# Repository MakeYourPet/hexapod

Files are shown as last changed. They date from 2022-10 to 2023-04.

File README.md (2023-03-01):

##
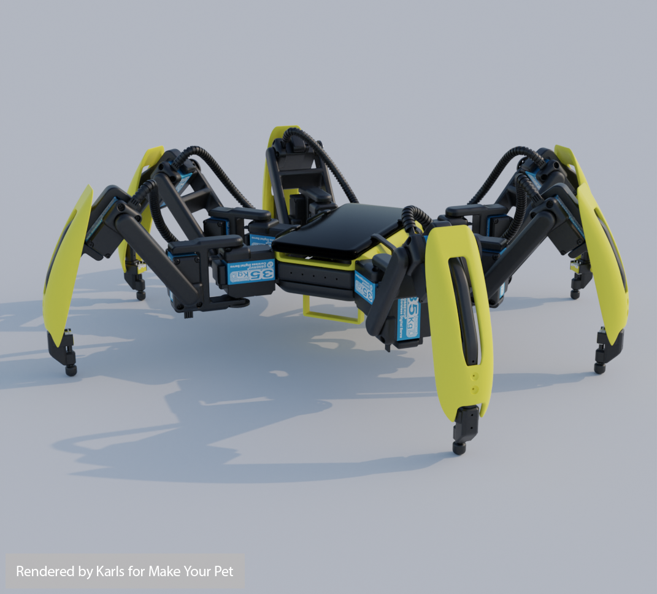
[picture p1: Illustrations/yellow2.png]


## Some quick links to get you started
- Watch the step by step build videos on my [YouTube channel](https://www.youtube.com/makeyourpet).<br>
- For build questions and to connect with the community join my [Discord server](https://discord.gg/vb8YWMfBuk).<br>
- A [wiring diagram](/wiring-diagram-servo2040.png) that you may find useful.<br>
- A fan-made [parts list](https://docs.google.com/spreadsheets/d/1jLi3IdmLERsBDhjaqHxFGQgZul_3uq9oj55M1rFG8mY/edit#gid=0). Also another fan-made [parts list](https://docs.google.com/spreadsheets/d/1y--z7EeejWcb-8ooPaIFn3Hulu9dJOcoKyGoxGq8KI8/edit?usp=drivesdk). And here is a [third one](https://github.com/LonelyGhost6/Public/blob/main/part-list.pdf). These are not meant to be a complete list of EVERYTHING that you need, but they cover most of the important and pricier stuff.<br>
- If you decide to use the Servo2040 board (highly recommended), find the [firmware](https://github.com/EddieCarrera/chica-servo2040-simpleDriver/releases/download/v0.0.1/chica-servo2040_release.uf2) and the [instructions on how to flash it](https://github.com/EddieCarrera/chica-servo2040-simpleDriver#loading-the-firmware-image) from Eddie's repository.<br>
  
## Illustrations
<p float="left">
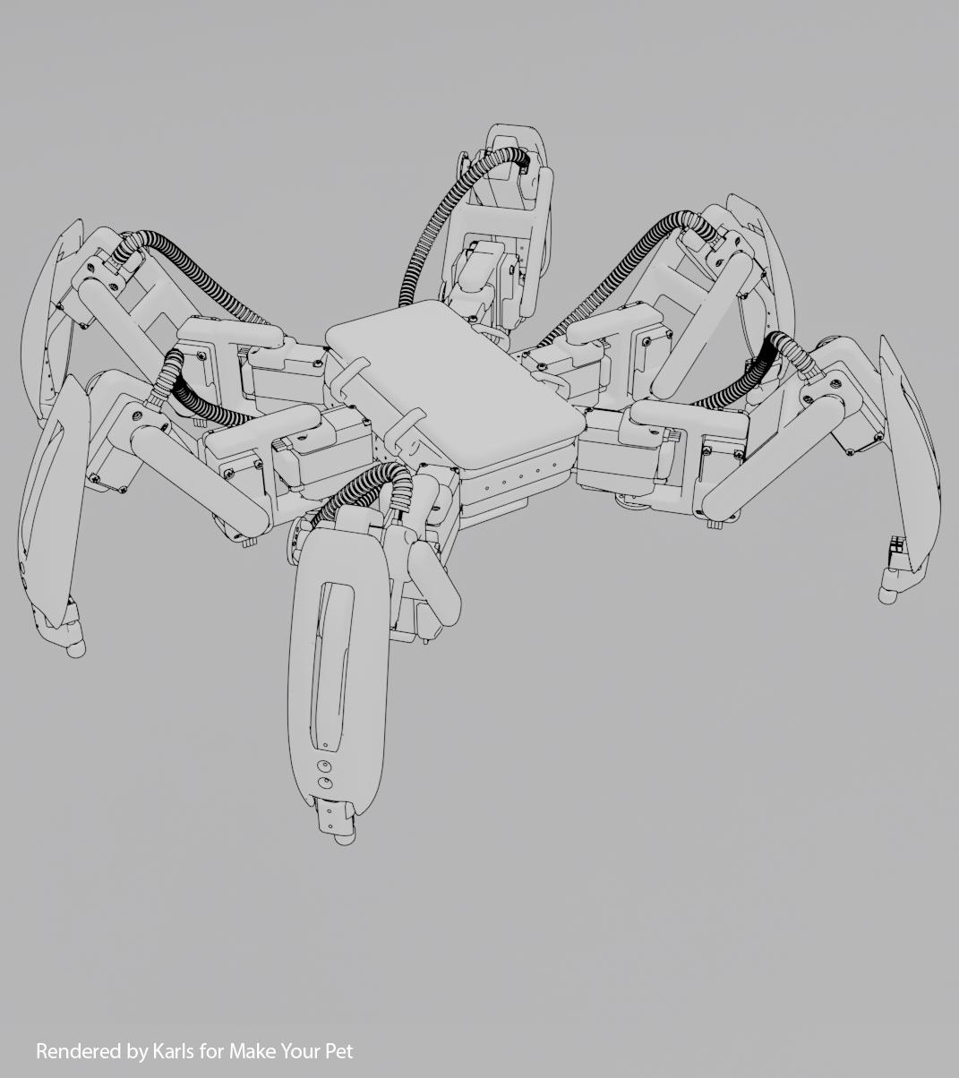
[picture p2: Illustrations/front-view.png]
  
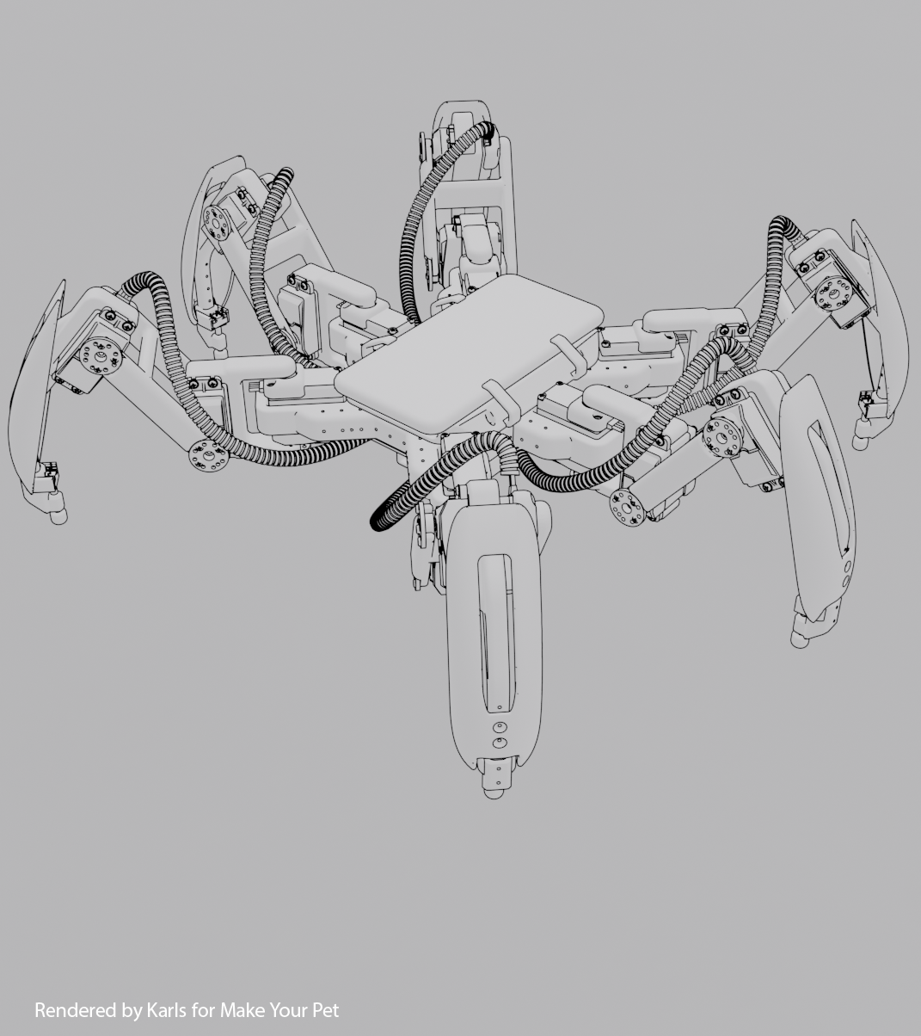
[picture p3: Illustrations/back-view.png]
  
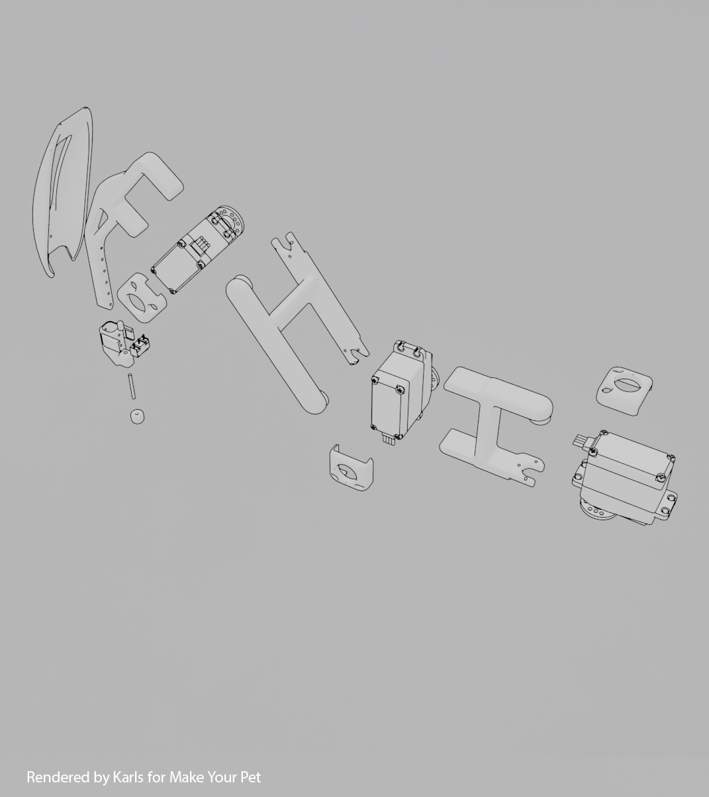
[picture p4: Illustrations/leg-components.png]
  
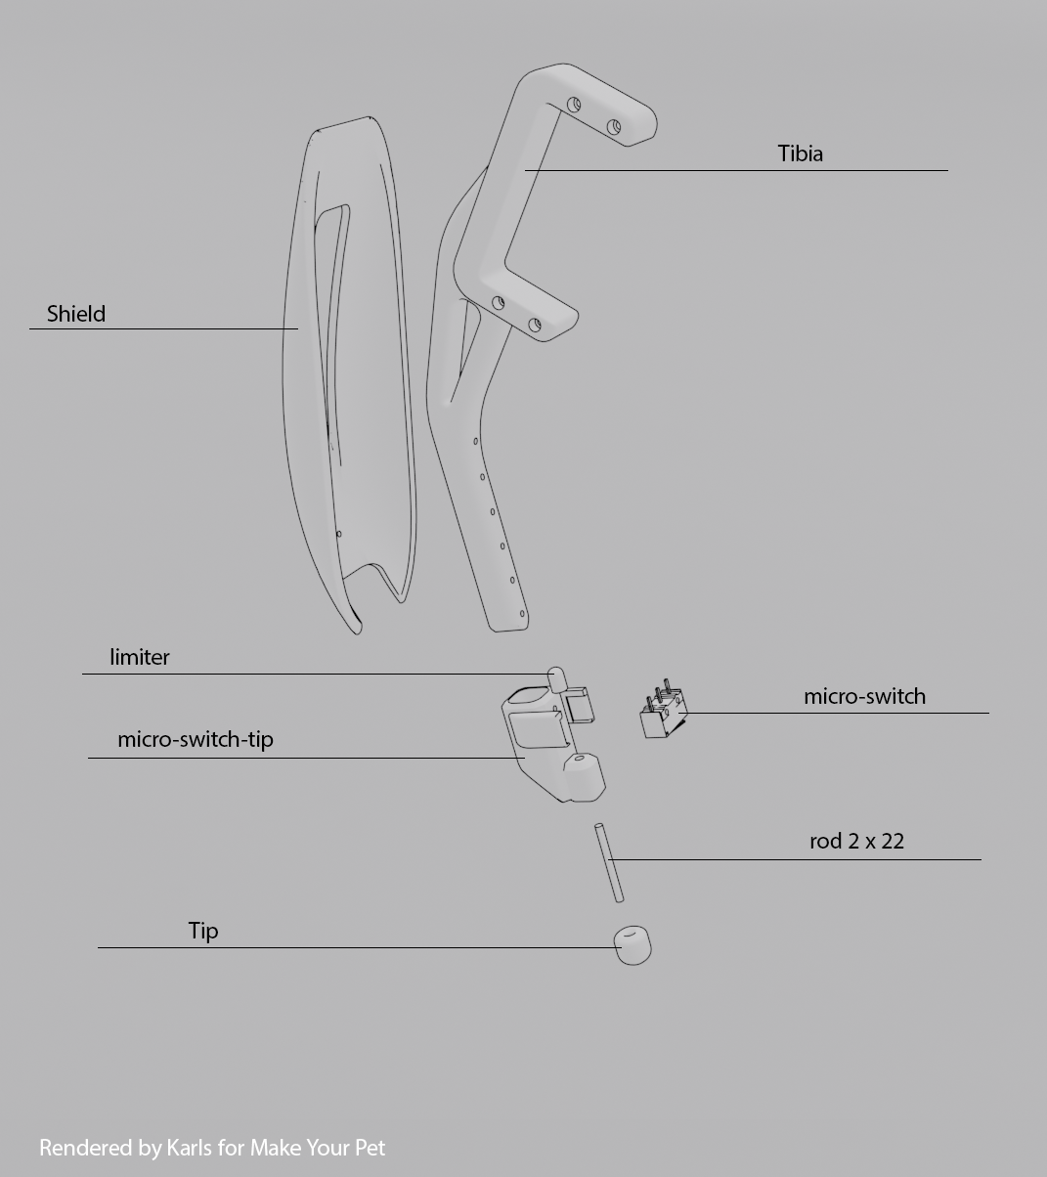
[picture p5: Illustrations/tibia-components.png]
  
</p>

## About the STL files in this repository
Some of the parts have multiple versions with slight differences. But all of them are compatible and should work.  
Make sure to check all of them to pick the one that works for you before committing to the print.  
I use the latest version of each part in my own hexapod, which is the one with the higher number at the end of its name.

## Compatible fan-made 3D printable parts
Check out [this](https://github.com/almelnz2005/hexapod) repository which contains modified (but compatible) versions of the original parts which uses metal horns, M3 screws and seperated components to make the parts more 3D printer friendly. This is especially helpful if you are printing with material other than PLA and have issues with supports or shrinking.

## Wiring Diagram
- Pimoroni Servo2040 (The newer, simpler, cheaper and recommended option):<br>
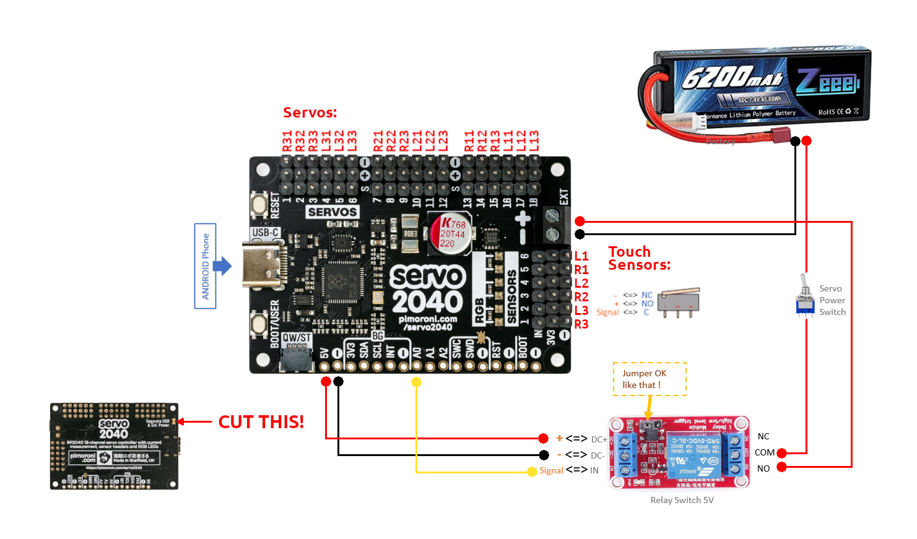
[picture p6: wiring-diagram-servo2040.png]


- Pololu Maestro (The original, complicated, expensive and legacy option):<br>
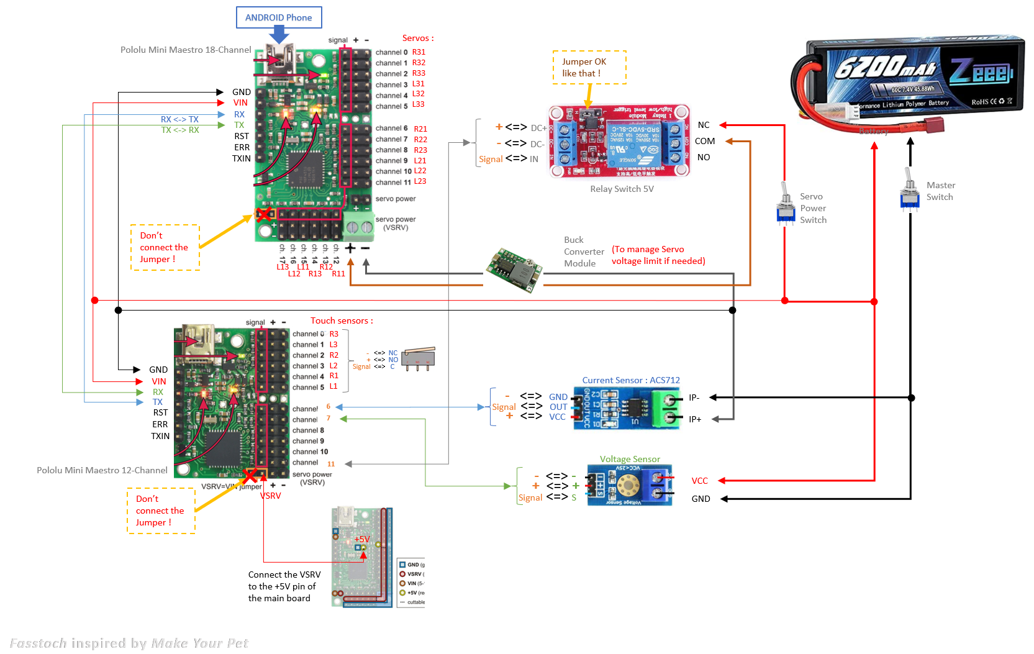
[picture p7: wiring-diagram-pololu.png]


## Electronic Component Layout
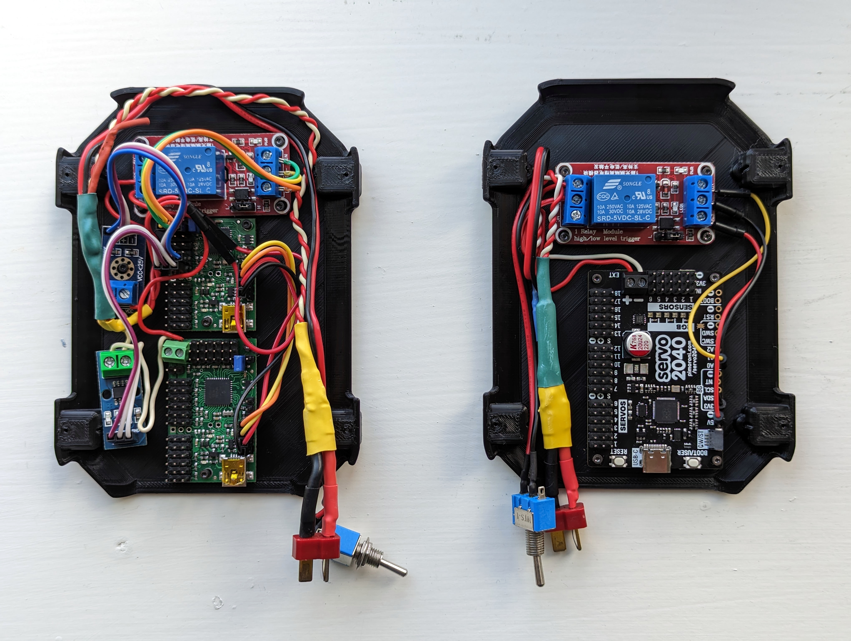
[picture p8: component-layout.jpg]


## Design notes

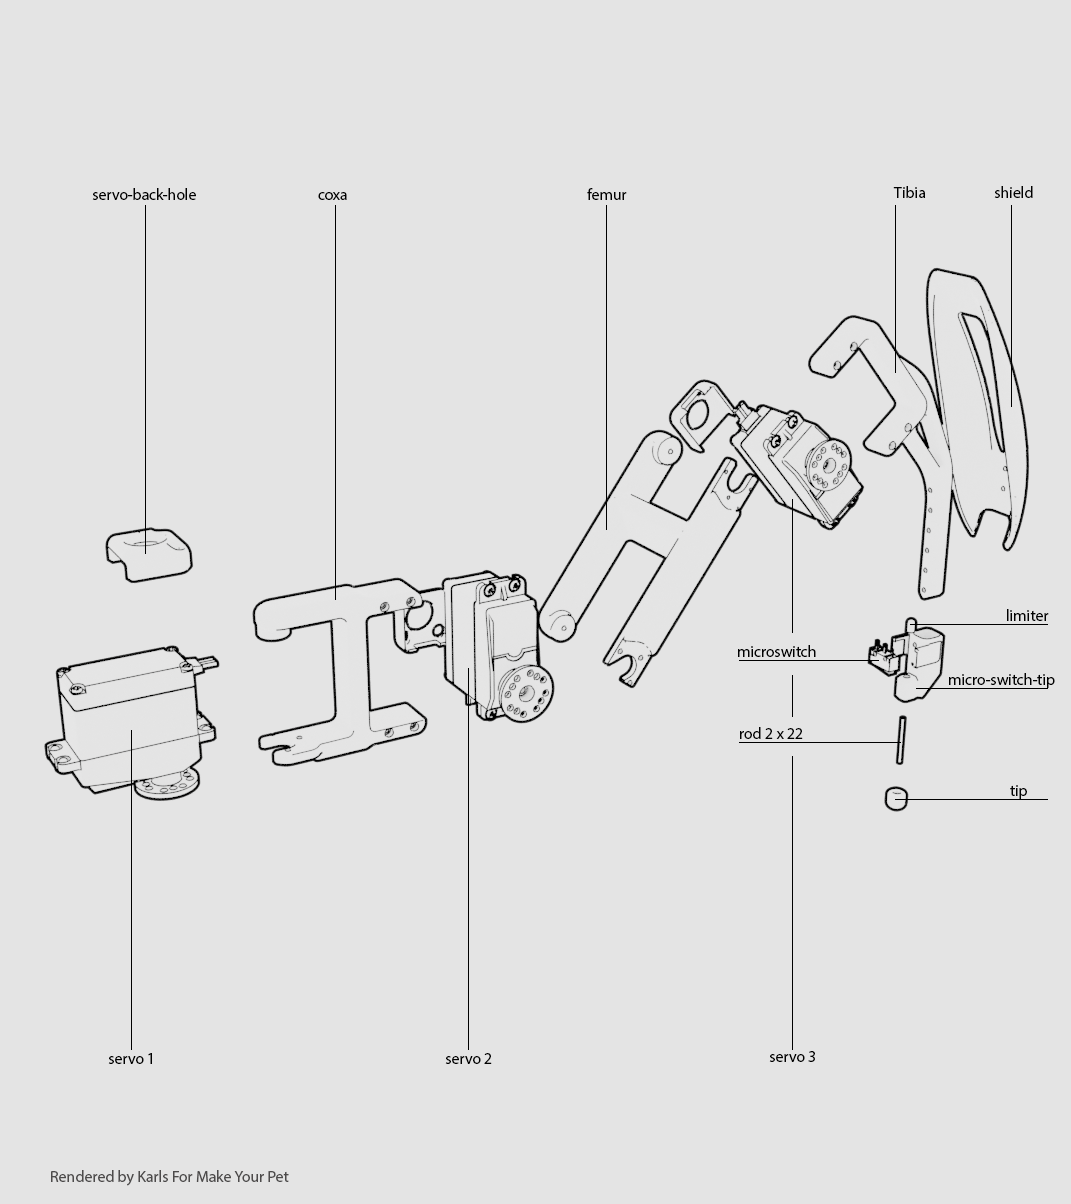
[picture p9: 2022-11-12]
Illustrations/leg.png

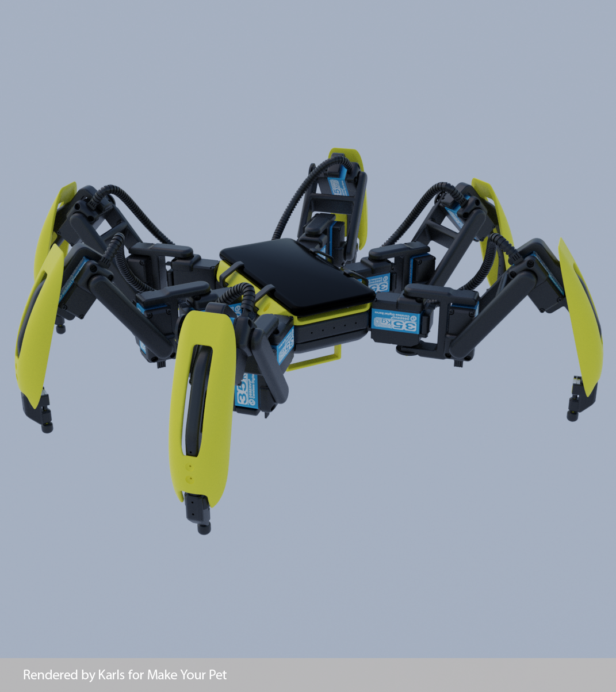
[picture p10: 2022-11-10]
Illustrations/yellow.png

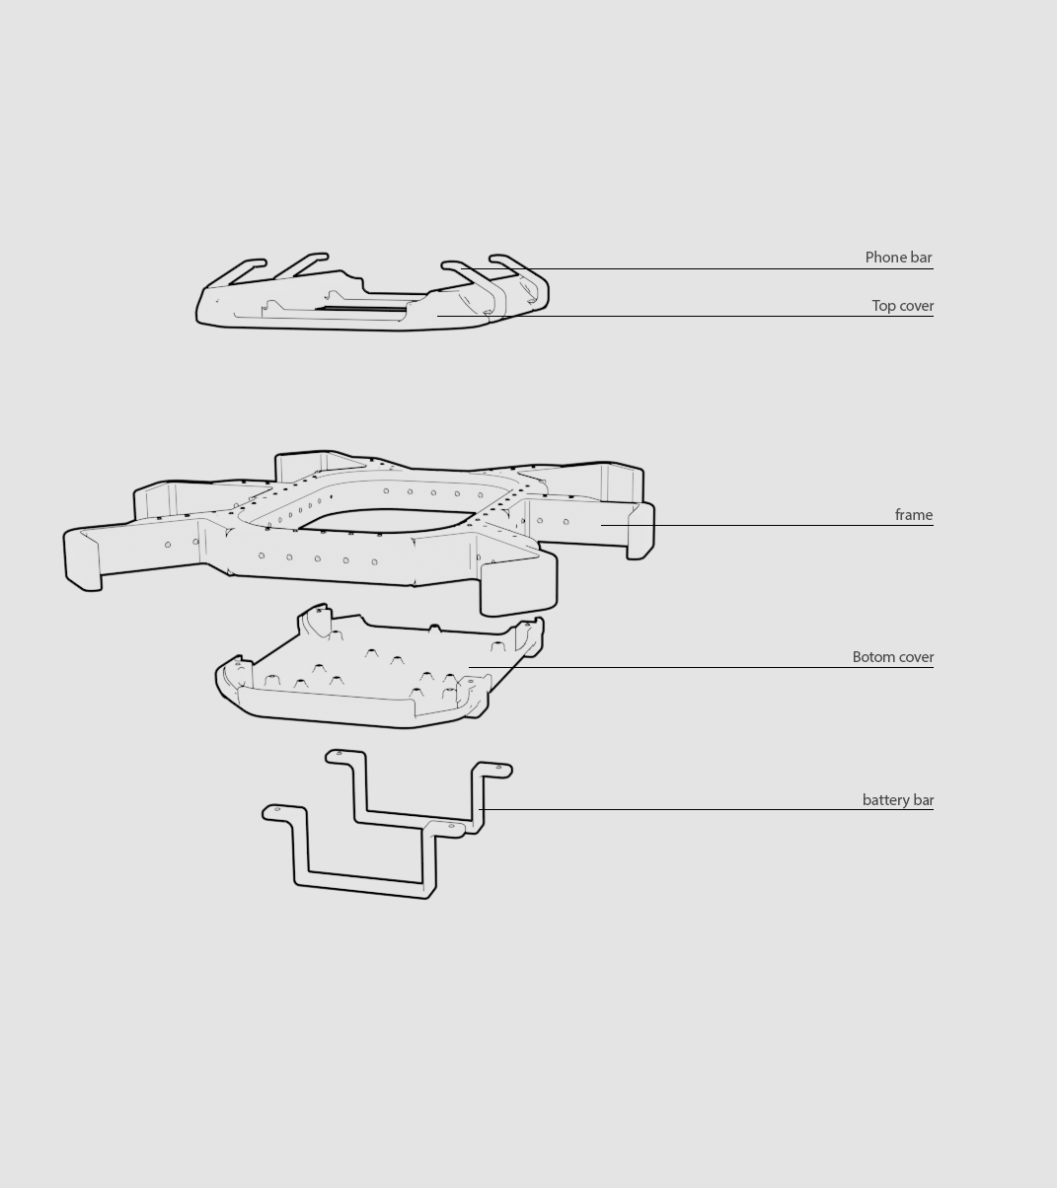
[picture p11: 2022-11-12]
Illustrations/body.png

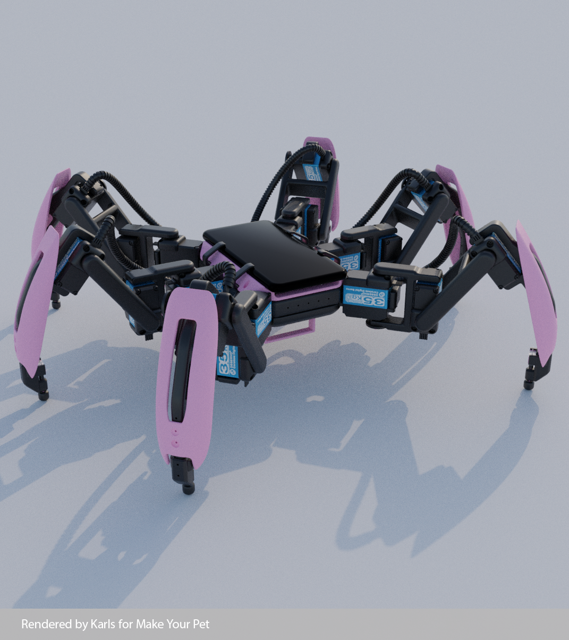
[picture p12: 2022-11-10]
Illustrations/Pink.png

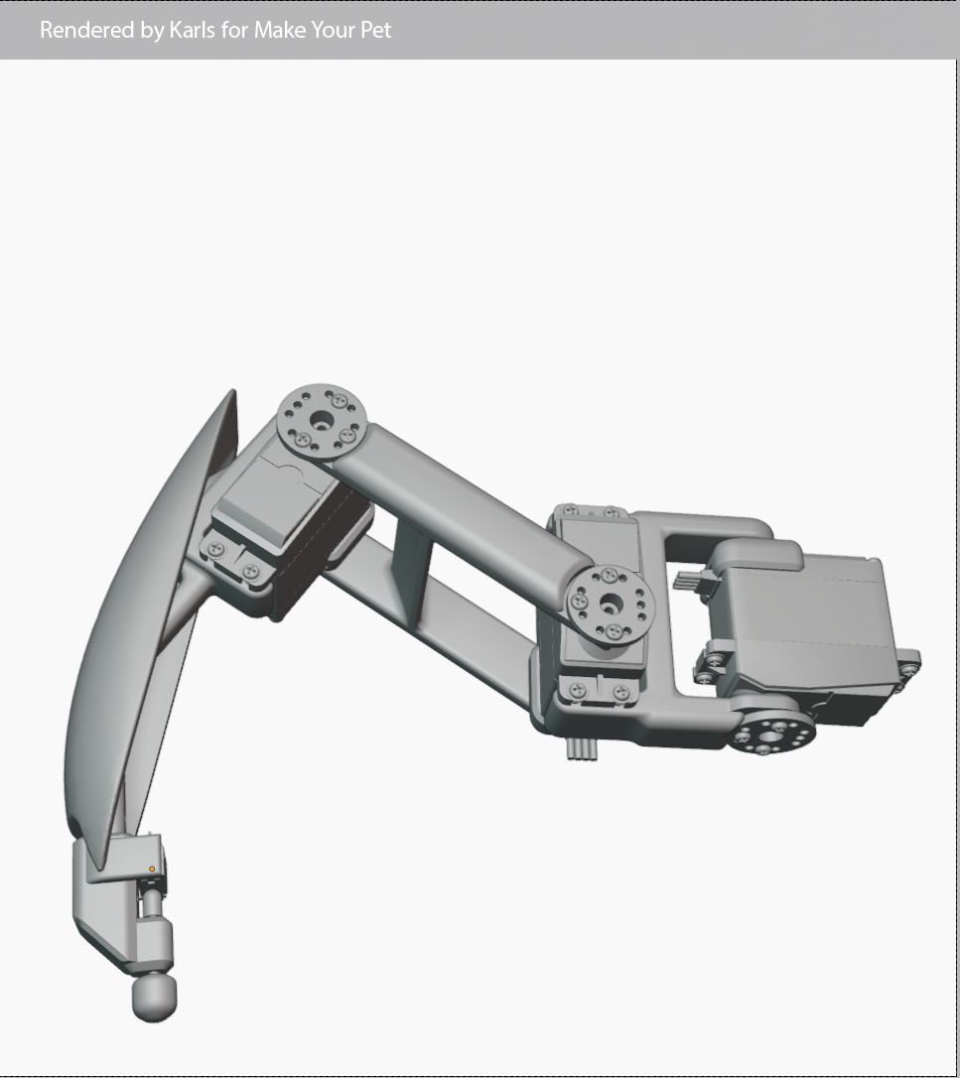
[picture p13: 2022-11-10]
Illustrations/servo_orientation.png

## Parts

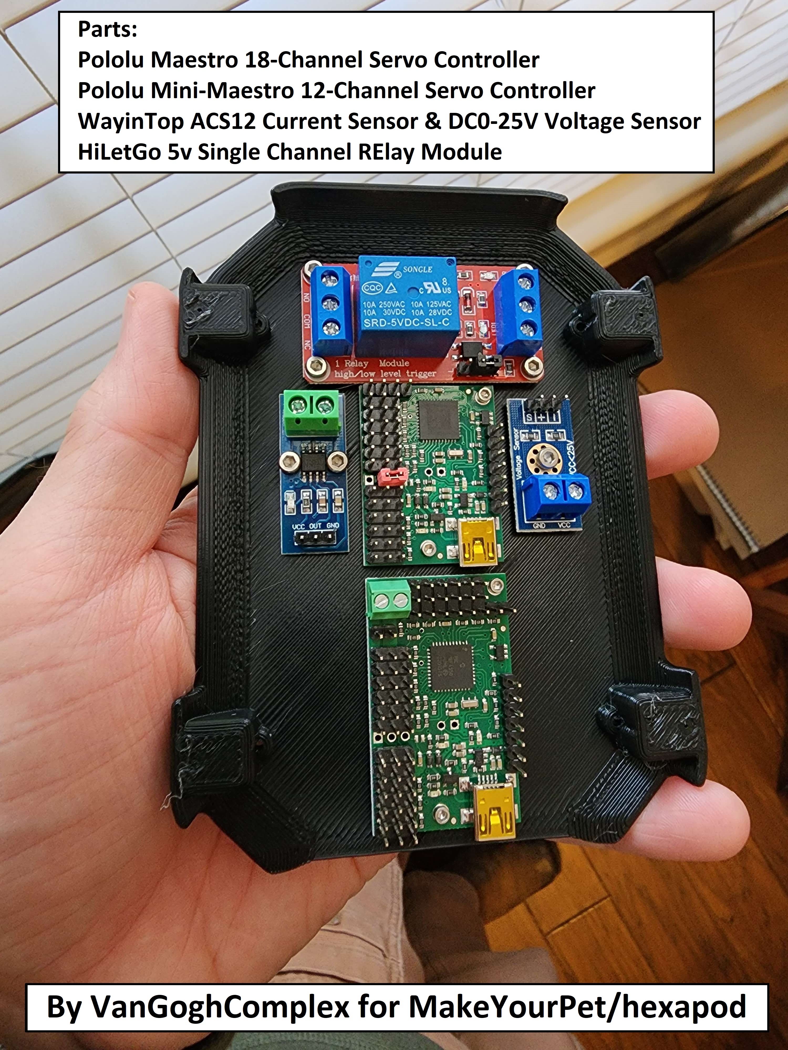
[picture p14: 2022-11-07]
component-layout-pololu.jpg

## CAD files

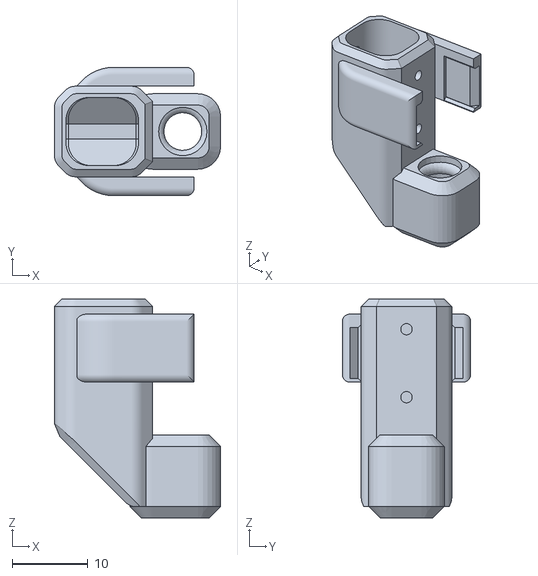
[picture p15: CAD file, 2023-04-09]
Chipo/ms-holder.stl
22.0 x 17.0 x 29.0

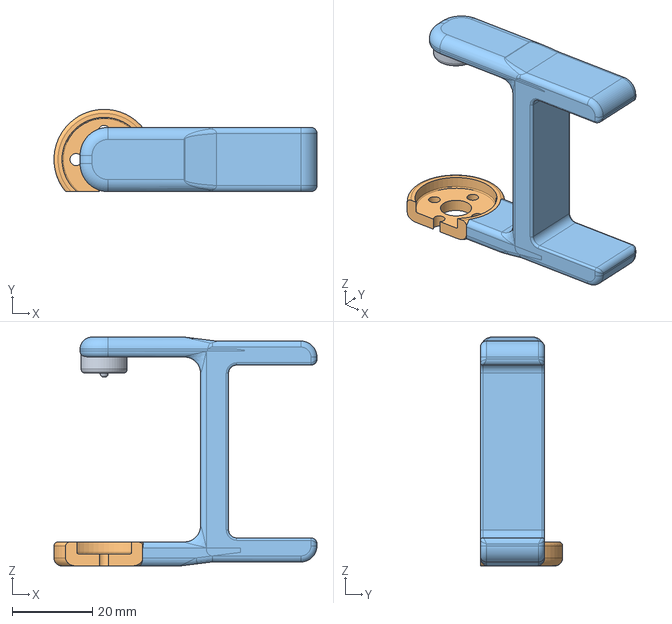
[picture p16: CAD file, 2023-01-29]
Metal Horn/STEP/coxa.step
65.5 x 20.5 x 57.0 mm

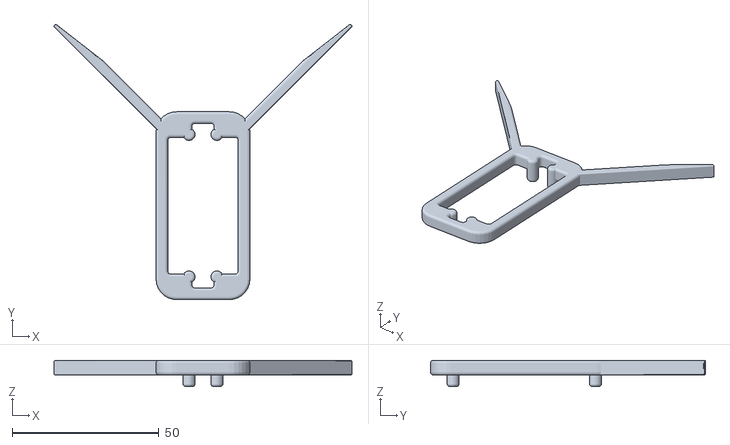
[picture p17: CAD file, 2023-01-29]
Metal Horn/STL/calib-ruler.stl
101.5 x 93.8 x 9.00

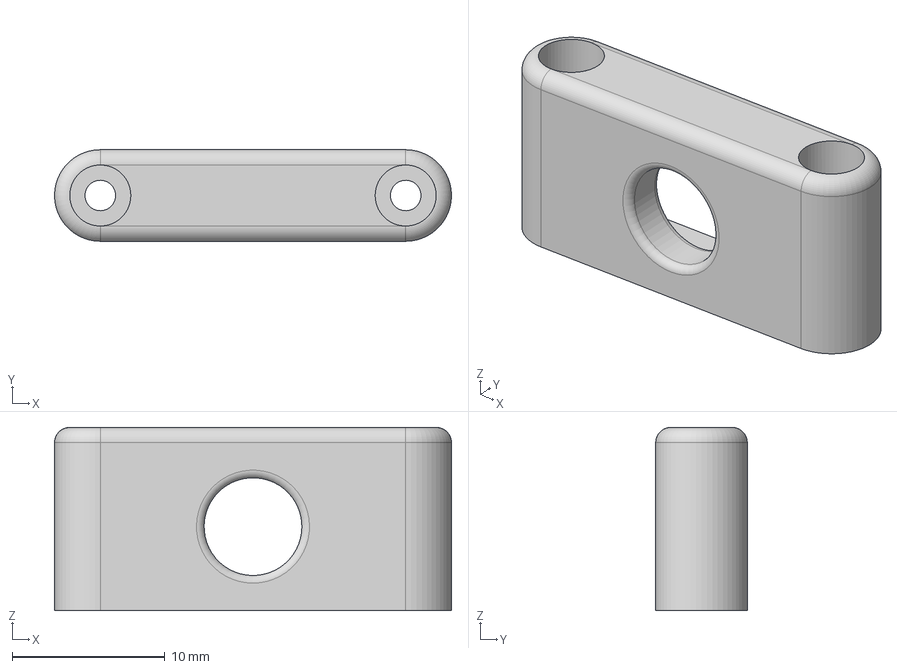
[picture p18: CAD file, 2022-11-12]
STEP/switchmount.step
26.0 x 6.00 x 12.0 mm

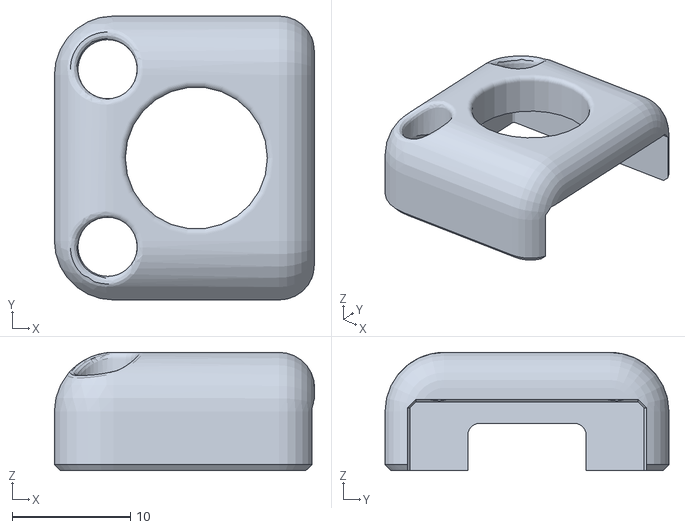
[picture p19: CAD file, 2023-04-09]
Chipo/idler.stl
22.0 x 24.0 x 10.0

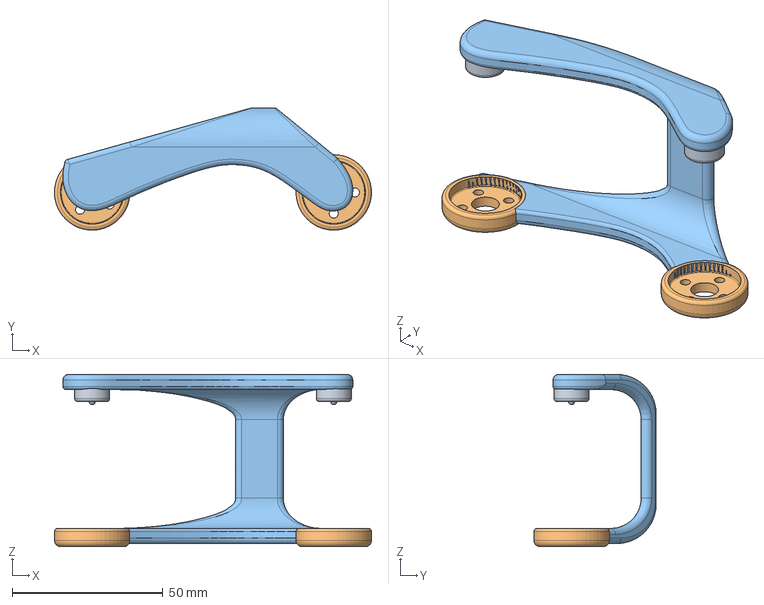
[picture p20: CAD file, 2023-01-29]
Metal Horn/STEP/femur.step
105.0 x 40.5 x 57.0 mm

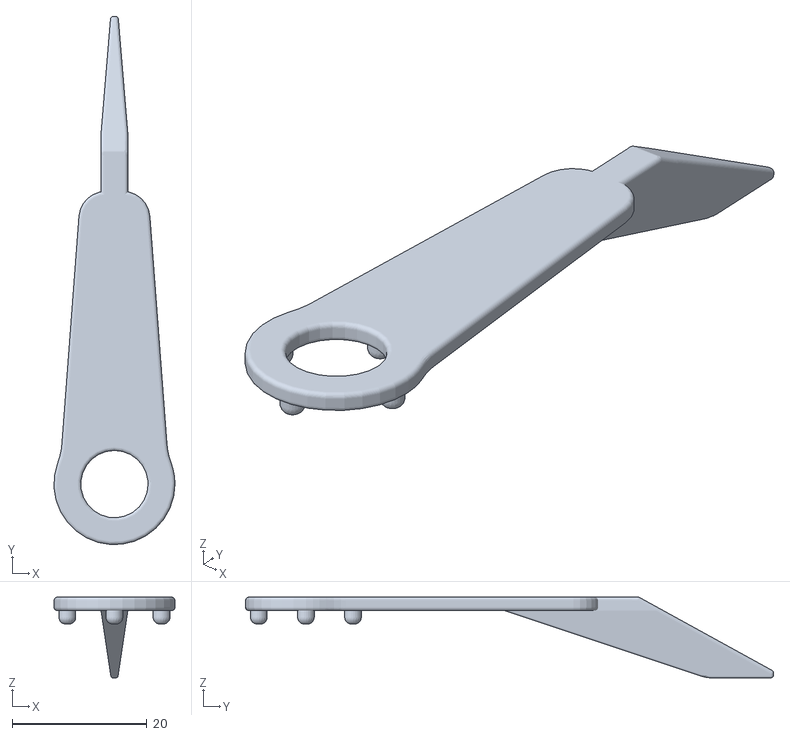
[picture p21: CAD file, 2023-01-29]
Metal Horn/STL/calib-arm.stl
18.0 x 78.5 x 12.0

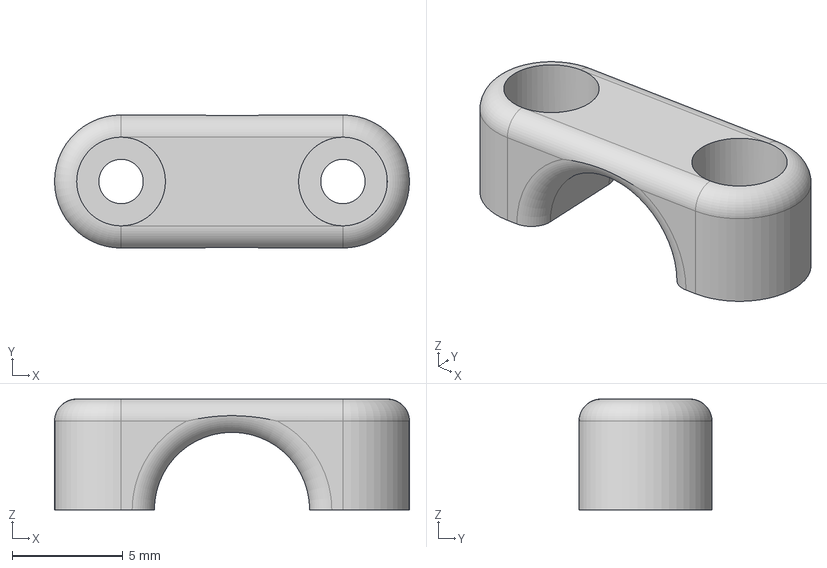
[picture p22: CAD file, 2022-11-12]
STEP/ziptiebase.step
16.0 x 6.00 x 5.00 mm

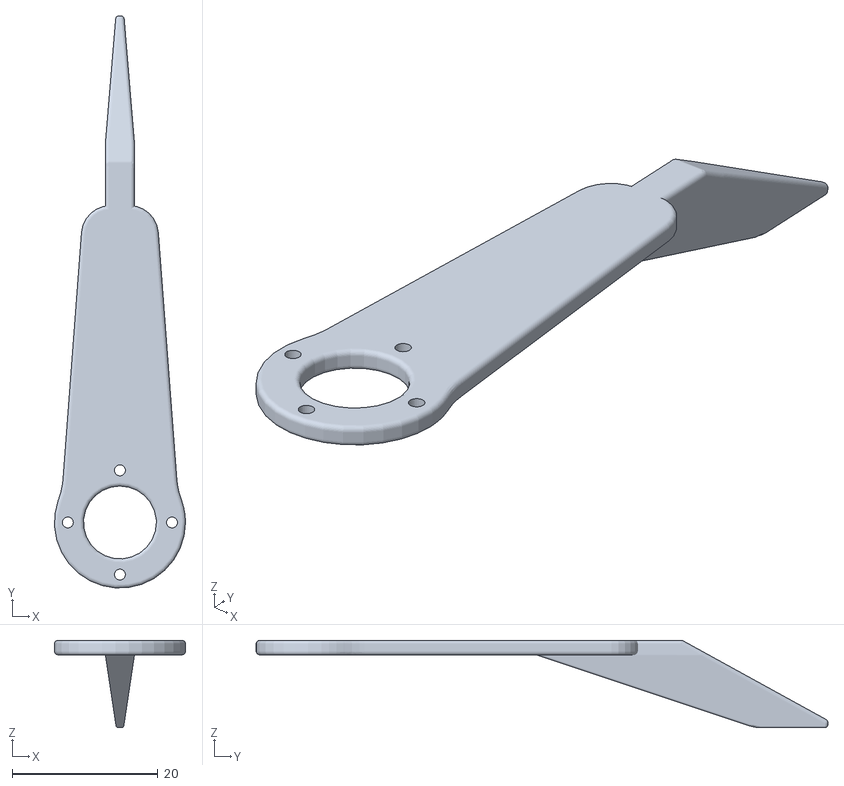
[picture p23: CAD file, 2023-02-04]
STL/calibration-arm.stl
18.0 x 78.5 x 12.0

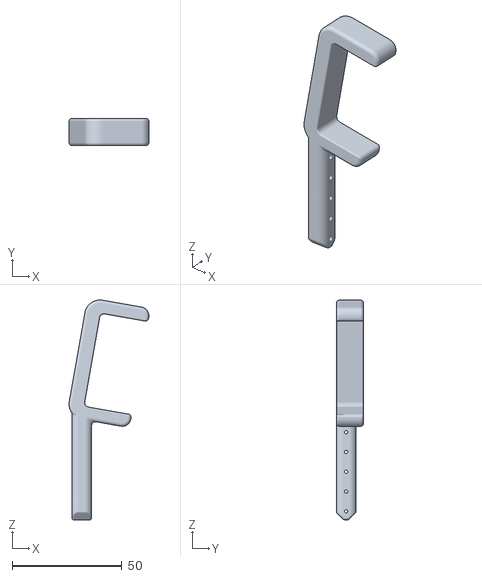
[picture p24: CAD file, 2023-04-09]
Chipo/tibia-996.stl
36.4 x 12.5 x 100.1

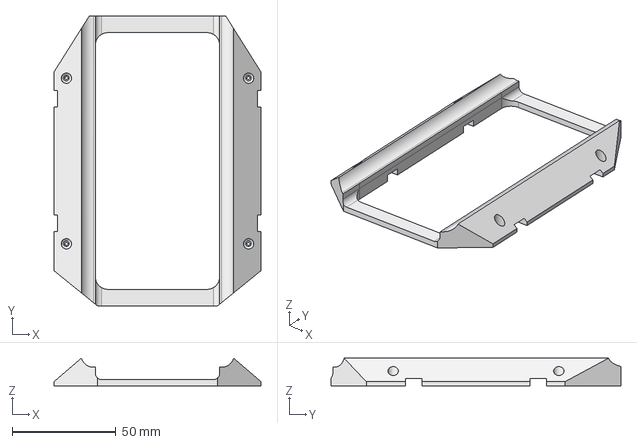
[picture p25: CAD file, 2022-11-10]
STEP/top-cover-no-fillet.step
100.0 x 140.0 x 13.3 mm

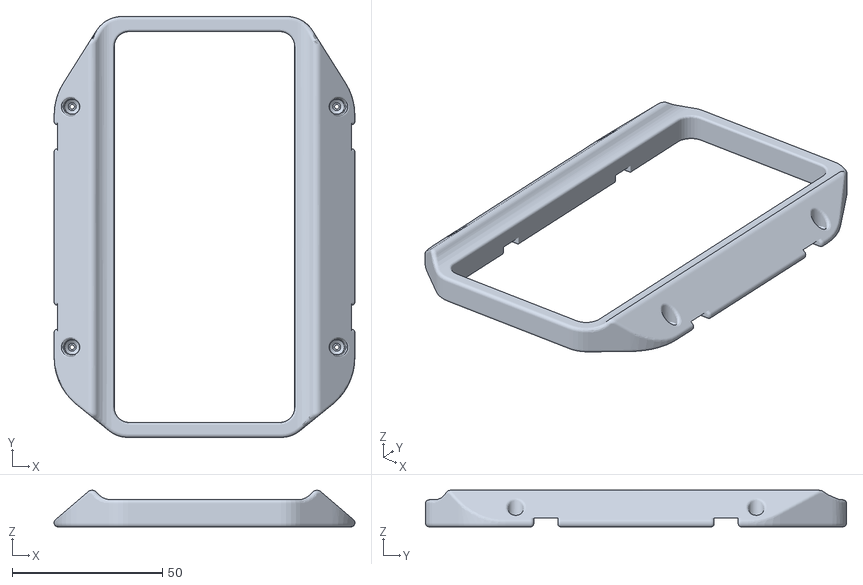
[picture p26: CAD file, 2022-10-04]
STL/top-cover3.stl
100.0 x 140.0 x 12.2

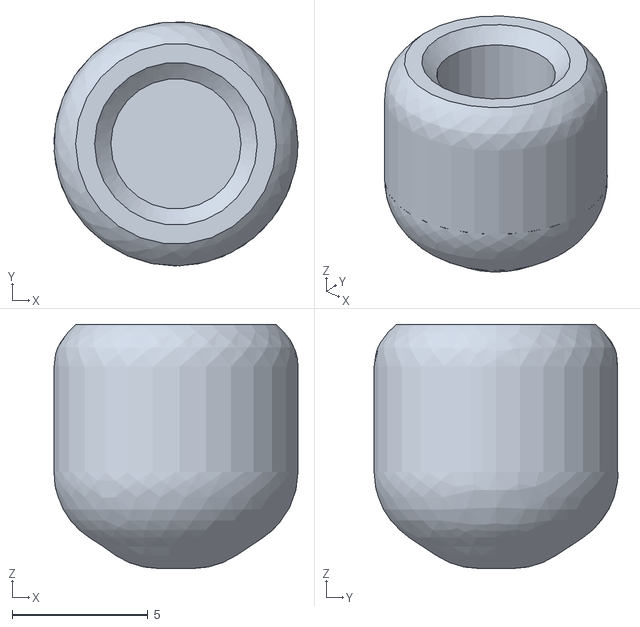
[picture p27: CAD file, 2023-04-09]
Chipo/tip.stl
9.00 x 8.99 x 9.00

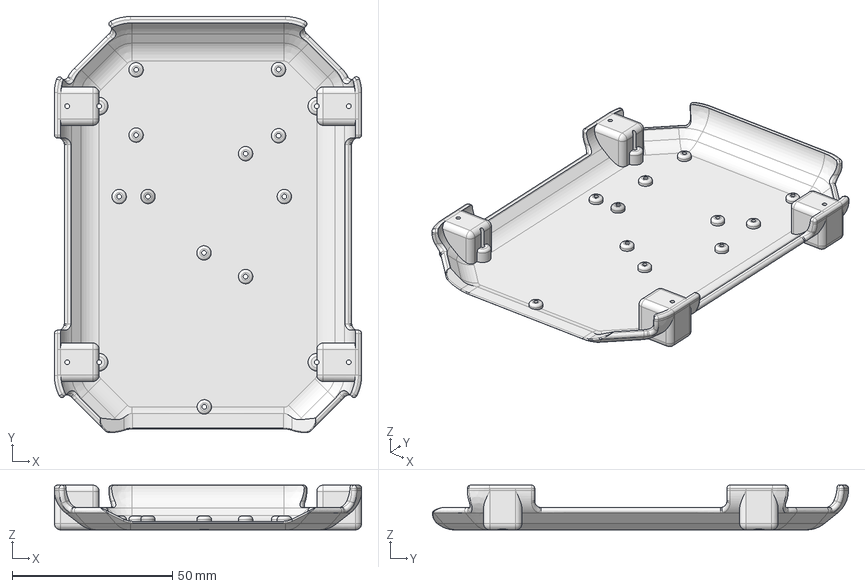
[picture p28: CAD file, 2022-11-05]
STEP/bottom-cover.step
96.0 x 130.0 x 14.0 mm

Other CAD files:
STL/calibration-ruler.stl
STL/right-femur.stl
Chipo/rod.stl
STEP/bottom-cover-flat.step
Chipo/coxa-996.stl
Chipo/femur-996.stl
Chipo/limitter.stl
Chipo/ring.stl
Metal Horn/STL/coxa.stl
Metal Horn/STL/femur.stl
STEP/coxa.step
STEP/femur.step
STEP/frame.step
STEP/limiter.step
STEP/micro-switch-holder.step
STEP/phone-bar.step
STEP/servo-back-hole.step
STEP/tibia.step
STEP/tip.step
STEP/top-cover.step
STL/battery-bar.stl
STL/bottom-cover-flat.stl
STL/bottom-cover.stl
STL/frame.stl
STL/left-coxa.stl
STL/left-coxa2.stl
STL/left-femur.stl
STL/left-tibia.stl
STL/limiter.stl
STL/micro-switch-tip.stl
STL/phone-bar.stl
STL/phone-bar2.stl
STL/right-coxa.stl
STL/right-coxa2.stl
STL/right-tibia.stl
STL/servo-back-hole2.stl
STL/shield.stl
STL/tip.stl
STL/top-cover.stl
STL/top-cover2.stl
STL/top-cover4.stl

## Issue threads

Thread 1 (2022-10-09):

Please add a README.md

johnsabilla, 2022-10-09:
Please add a README.md ty ty

moebis, 2022-10-09:
Missing parts list too. BTW, thanks for this awesome project. Really excited to start on it.

ARobBot, 2022-10-17:
A bill of materials would be greatly appreciated. Ta

SupMap, 2022-10-18:
Awesome project!

A parts list would be a very great addition, also maybe releasing the apps (software) as open source so others can contribute?

Thanks!

johnsabilla, 2022-10-18:
all of these are just .STL files so just the 3D printable parts. It doesn't include the other electronic hardware.

Beenay25, 2022-10-24:
I'd just be happy knowing what size the servos are. 😁

moebis, 2022-10-24:
I think this project might have died before it took off. Just radio silence. Too bad, I kinda thought it was promising.

MakeYourPet, 2022-10-24:
>

README and LICENSE files are coming, but so many people are already building this hexapod and didn't need those to get started, and unfortunately I have other priorities.

On a separate note, comments like this are one of the main reasons that I am not open-sourcing my code.

Beenay25, 2022-10-24:
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

We do appreciate all your work on the project. It's exciting!
I can imagine many people have been able to make their own with little instruction. Some of us are more noobs and might need a bit more direction.

I'll get there eventually, but I'm really looking forward to getting specs and parts lists to help. 😁

MakeYourPet, 2022-10-24:
I understand, and appreciate your interest in this project as well. Then I would suggest for you to hold off a month or two, until we resolve all the issues and refine the hard edges while some others finish building their hexapods. Because in the current format you would need to be able to pick your electronics and finish the wiring on your own, and I don't have a detailed step by step assembly instructions ready yet.

johnsabilla, 2022-10-24:
Just join their discord. Lots of people are ahead of building the pod

MakeYourPet, 2022-10-25:
Go to www.makeyourpet.com and click on the Discord button to join. Thank you.

MakeYourPet, 2022-10-25:
I also added some of the useful links to the README file. I was under the impression that all of the folks here know about my YouTube channel and my Discord server. Now your comments make sense. I hope you build and enjoy the hexapod.

MakeYourPet, 2022-10-25:
And just added a fan-made wiring diagram and two separate fan-made parts lists.

Beenay25, 2022-11-08:
This is all looking so good now! Exciting!

Thank you so much for all the updates.

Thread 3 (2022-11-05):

Configurable Responses to Undervoltage/Overcurrent

VanGoghComplex, 2022-11-05:
Set variables in the config file to the robot's responses to low voltage or high current have adjustable reactions.

Variables:
- High Current Warning
- High Current Critical
- Low Voltage Warning
- Low Voltage Critical

Reactions (for each variable)
- None
- Visual Alarm
- Visual and Auditory Alarm ( bonus feature - select local sound files for alarms! 😄 )
- Servo power kill

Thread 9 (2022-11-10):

Client App UI Suggestions

VanGoghComplex, 2022-11-10:
1.) Add a silhouette or transparent graphic or something to the software joystick to indicate that the left side of the screen is the front of the robot

2.) Color code or group buttons into categories:
   - Static motions like Dive and Flex
   - Gaits and modifiers like Crabwalk
   - Single action commands like home, jump and bounce

3.) Current and voltage readings on the Client UI would be helpful

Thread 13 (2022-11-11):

Manage multiple height of floor

Fasstoch, 2022-11-11:
Allow the hexapod to move over rough terrain with multiple heights.

EddieCarrera, 2023-03-12:
I think using the touch sensors along with a slower single-leg movement gait can do a good job of achieving this. The hexapod can go through rough terrain by using the TS to know that height at which the leg needs stay at before moving the following legs.

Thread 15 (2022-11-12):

Tip should be 1mm smaller

wdewind, 2022-11-12:
Out of the initial 6 tips that I printed only 1 allowed full movement of the dowel to allow the switch to click.  I suspect the measurements are correct but the tolerance is very low, so to make this have a slightly wider margin of error we can just cut 1mm from this model.  I tried messing with the limiter a bit, but ultimately found it much easier to simply cut the bottom millimeter off the tip in prusaslicer.  To preserve the aesthetic we should just take 1mm from the middle of the model.

I'm happy to do this when I get around to it, mostly just wanted to create this issue to track since multiple people in the discord have mentioned having issues with this part.

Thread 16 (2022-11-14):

Explore the use of Adafruit board PCA9685 or Arduino board

marcosncosta1, 2022-11-14:
I don't have access to a Pololu servo controller, so I will try to use Adafruit PCA9685 along with Arduino for the servo controls. Will submit the solutions as I go along with the process.

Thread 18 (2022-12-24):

Hi there

Kifmanks, 2022-12-24:
I am making one hexapod according to all the material on the list and wired all the cable and components according to the wire diagram but the hexapod have no response...

I don't no what the problem is..
It is weird that when I connect the phone to the hexapod, the client apps opens automatically. Two main board have orange and green lights on but there is no response even the touch sensor and all the servo.

Could anyone help on this?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

I have simply tried to connect one legs with a pololu 6channel board and connect to the phone and it has no response too.... is there anything I have missed? I am just a amateur in this field so I have no ideas what to do.
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

Anyway Merry Christmas to all of you!

MakeYourPet, 2022-12-25:
Merry Christmas to you too.
If you still have that problem, make sure to check my Discord channel (find from makeyourpet.com). Me and others who already build this project are there to help you with any questions that you may have.

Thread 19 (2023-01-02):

Great Project, finished at last

kike1978, 2023-01-02:
Hello everybody, at last after 1 month I received all the material from aliexpress and I started working on the hexapod. Definetively it is very minuciosous work but the robot plains and explications are very clear, therefore in 5 days I completed it with successful.
now I can tell it, it is cool! Thank you maker ;)

spinorose, 2023-03-19:
what servo did you purchase on ali express ? can you share a link ?

kike1978, 2023-03-19:
https://es.aliexpress.com/item/33010787343.html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

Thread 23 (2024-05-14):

Hexapod rubber tip wrong diameter wrong

silvertakana, 2024-05-14:
based on the [partlist](https://docs.google.com/spreadsheets/d/1y--z7EeejWcb-8ooPaIFn3Hulu9dJOcoKyGoxGtoq8KI8/edit#gid=0) provided in the `README.md`, the diameter of the rubber tip cover was 8mm. but the `tip.step` has a diameter of 9mm. I only just realized this after printing it out and will have to redesign to make it 8mm like the rubber tip. Luckily, I haven't mass printed them, so the issue was easy to fix. That aside, what should the diameter of the tip be? Does it even matter?

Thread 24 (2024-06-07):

Can you use 360° servo instead of 180°?

Snoozer-94, 2024-06-07:
Hey, yh the title pretty much asks the question. Looking into buying some servos and found that the 360 are cheaper than the 180, was wondering if that would be an issue at all. Have experience with electronics and some coding but when it comes to robotics I'm pretty new.

Snoozer-94, 2024-06-10:
Pretty much answered my own question through research, for anyone wondering basically 360 servos (aka continuous servos) don't use the values in the code the same way 180 servos do. Instead of the servo be set to a specific angle, it instead uses that value to set the speed in which the gears rotate. It is possible to change the code to have fixed values but I personally don't want to change the app provided just incase I mess it up in some way. Also I am still a novice when it comes to coding.

TLDR: Get 180° servos, not the 360° servos.

piyushdotcomm, 2025-06-21:
360° servos will be better for full controlled movement. As 180° servos might have some limitations.

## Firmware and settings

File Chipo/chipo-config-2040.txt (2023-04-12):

# Any line that starts with a # is a comment.
# Servo names: L11 L12 ... L33 R11 ... R32 R33
# Pin names: P0 ... Pn on the (P)rimary board
# Pin names: S0 ... Sn on the (S)econdary board

# Servo pins and servo calibration values
#
# Format: [Servo name] [Pin name] [-45 usec] [+45 usec]
L11 P15 1995 980
L12 P16 1960 945
L13 P17 2020 1040
L21 P09 2005 1005
L22 P10 1965 970
L23 P11 2005 1010
L31 P03 2020 1060
L32 P04 2050 1065
L33 P05 1945 970
R11 P12 1930 920
R12 P13 2040 1060
R13 P14 2010 1015
R21 P06 1990 1010
R22 P07 1930 945
R23 P08 2040 1050
R31 P00 2020 1050
R32 P01 2045 1080
R33 P02 1970 960

# Touch sensor pins
# Removing a sensor definition will disable that sensor.
#
# Format: [Touch sensor name] [Pin name] [High Active: 0 or 1]
TS_L1 P23 1
TS_L2 P21 1
TS_L3 P19 1
TS_R1 P22 1
TS_R2 P20 1
TS_R3 P18 1

# Voltage and Current sensor pins and calibration values
# Removing a sensor definition will disable that sensor.
#
# Format: [Sensor name] [Pin name] [Pin voltage to read 0] [Pin voltage to read 1]
CUR P24 2.5 2.444
VOL P25 0.0 0.2

# Voltage and Current warning and shut off levels.
# The levels are upper limits for current, and lower limits for voltage readings.
# Warning/Shut off will get triggered if the reading stays in the specified level for more than
# "Activation duration" seconds.
#
# Format: [Sensor name] [Activation duration] [Warning level] [Shut off level] [Beep count]
WARN_CUR 2 5 7 3
WARN_VOL 2 5.4 5 3

# Relay switch for the main servo power
# Remove this line if you do not have a relay.
#
# Format: [Output] [Pin name] [High Active: 0 or 1]
RELAY P26 1

# The placement of the legs and animation settings
#
# Format: [Mode name] [Leg radius] [Corner leg angle] [Elongation] [Body Lift]
#         [Step lift] [Vertical touch sensors correction] [Speed factor] [Animation factor]
MODE_STANDARD  190 55 1.15  40 30  10 0.7 1.0
MODE_RACE      190 55 1.20  35 20   0 1.0 0.0
MODE_OFFROAD   210 55 1.15  60 60 120 0.6 1.0
MODE_CUSTOM    190 55 1.15  40 40  10 1.0 1.0
MODE_QUADRUPED 210 60 1.00  45 30   0 0.7 1.0
MODE_BLOCK     185 30 1.07 -40 80   0 1.0 1.0

# Length of leg segments in millimeters
COXA_LEN 43
FEMUR_LEN 60
TIBIA_LEN 104

# Distance between the coxa rotation centers of different legs in millimeters.
L1_TO_R1 126
L1_TO_L3 167
L2_TO_R2 163

# The height where the legs connect to the frame.
LEG_CONNECTION_Z -7
# The Z value for the leg endpoints when sitting on a flat surface.
LEG_SITTING_Z -40

# The angle between the servo itself and the leg segment when the servo is centered.
COXA_ATTACH_ANGLE -8
FEMUR_ATTACH_ANGLE 35
TIBIA_ATTACH_ANGLE 83
















# this is intentional.

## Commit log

2022-10-04 Initial commit
    There are multiple versions of some parts with slight differences. I kept all of them in case you prefer the old ones better.
    [battery-bar.stl, bottom-cover.stl, frame.stl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]
2022-11-04 Add files via upload
    Added new STEP file for a smooth bottom cover to allow for drilling and setting your own standoffs.
    [bottom-cover-flat.step]
2022-11-04 Add files via upload
    Added new STL file for a smooth bottom cover to allow for drilling and setting your own standoffs.
    [bottom-cover-flat.stl]
2022-11-05 Bottom cover with updated hole pattern
    Corrected 2-hole pattern for current sensing module: WayinTop ACS712
    [bottom-cover.step]
2022-11-05 Bottom cover
    Update to match changed STEP file
    [bottom-cover.stl]
2022-11-07 Photo of component layout
    Photo of layout for electrical components in case
2022-11-07 Update Image
    Added text for credit and BOM
2022-11-10 Move all stl files to STL folder
    [battery-bar.stl, bottom-cover-flat.stl, bottom-cover.stl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]
2022-11-12 Add ziptie base and switch mount
    These are based on the 10mm accessory hole patterns found on the legs and frame.
    [switchmount.step, ziptiebase.step]
